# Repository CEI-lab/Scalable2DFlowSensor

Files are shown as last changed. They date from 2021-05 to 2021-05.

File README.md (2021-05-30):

# Scalable2DFlowSensor

Repository for paper, A Customizable, Low-Cost Alternative for Distributed 2D Flow Sensing in Swarms, published in SWARMS2021 conference. 

This is an implementation of a 2D thermal flow sensor that uses a PCB with central heating element and 5 surrounding thermistors to sense both magnitude and direction of flow along a surface. See paper for details https://cei.ece.cornell.edu/publications/

This work is published for the purpose of helping other groups design their own thermal flow sensors. Details for use:

The calibration code folder contains the python and arduino code used in the calibration of the sensor. The sensor was designed to be read from any microcontroller with an analog read, we chose to use an arduino. The python code is then run from a computer connected over usb to the device to read data from the sensor. The purpose of this calibration is to find the proper offset values for accurate reading of direction and magnitude.

The field_test_code folder contains the python and arduino files used to read data from the sensor in the field. These files are quite simple because a key goal of the sensor was a simple interface. Even the arduino is overkill for this application. The python file here periodically saves the read data to a csv file with a unique generated file name. The test is concluded by interrupting the script with a keyboard interrupt which is caught and saves the remaining data to the file before terminating.

The other three folders flowSensorFlexible, flowSensorV2, and magArraySensor contain the PCB design files for the 3 versions of the sensor discussed. These files were created in Altium and can be used as is to order your own PCBs or can serve as inspiration to design your own geometries. These designs are quite simple, so recreating them in another program or to different specificiation should be straigh forward.

Published under the MIT Open Source Liscense.

Maintained by Jack A. Defay (user: jackdefay).

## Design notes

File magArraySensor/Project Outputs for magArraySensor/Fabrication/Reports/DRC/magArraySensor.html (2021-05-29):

Altium

# Design Rule Verification Report

Date: | | 8/11/2020
Time: | | 11:37:09 PM
Elapsed Time: | | 00:00:01
Filename: | | C:\Users\3jack\AppData\Local\TempReleases\Snapshot\3\magArraySensor.PcbDoc

Warnings: | | 0
Rule Violations: | | 0

## Summary

Warnings | Count
Total | 0

Rule Violations | Count
Clearance Constraint (Gap=10mil) (All),(All) | 0
Short-Circuit Constraint (Allowed=No) (All),(All) | 0
Un-Routed Net Constraint ( (All) ) | 0
Modified Polygon (Allow modified: No), (Allow shelved: No) | 0
Width Constraint (Min=10mil) (Max=10mil) (Preferred=10mil) (Disabled)(All) | 0
Power Plane Connect Rule(Relief Connect )(Expansion=20mil) (Conductor Width=10mil) (Air Gap=10mil) (Entries=4) (All) | 0
Hole Size Constraint (Min=1mil) (Max=100mil) (All) | 0
Hole To Hole Clearance (Gap=10mil) (All),(All) | 0
Minimum Solder Mask Sliver (Gap=10mil) (All),(All) | 0
Silk To Solder Mask (Clearance=10mil) (IsPad),(All) | 0
Silk to Silk (Clearance=10mil) (All),(All) | 0
Net Antennae (Tolerance=0mil) (All) | 0
Height Constraint (Min=0mil) (Max=1000mil) (Prefered=500mil) (All) | 0
Total | 0

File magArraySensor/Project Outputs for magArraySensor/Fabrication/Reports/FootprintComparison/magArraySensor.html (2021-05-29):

Altium customize

# Footprint Comparison Report

Date: | | 8/11/2020
Time: | | 11:37:11 PM
Elapsed Time: | | 00:00:00
Filename: | | C:\Users\3jack\AppData\Local\TempReleases\Snapshot\3\magArraySensor.PcbDoc

## Contents

Contents

Components Status Summary

Matched Components List

## Components Status Summary

## Matched Components List

Designator | Footprint | Footprint reference | Footprint to reference Library
J1 | PIN | PIN | C:\Users\3jack\AppData\Local\TempReleases\Snapshot\3\PcbLib1.PcbLib
J2 | PIN | PIN | C:\Users\3jack\AppData\Local\TempReleases\Snapshot\3\PcbLib1.PcbLib
J3 | PIN | PIN | C:\Users\3jack\AppData\Local\TempReleases\Snapshot\3\PcbLib1.PcbLib
J4 | PIN | PIN | C:\Users\3jack\AppData\Local\TempReleases\Snapshot\3\PcbLib1.PcbLib
J5 | PIN | PIN | C:\Users\3jack\AppData\Local\TempReleases\Snapshot\3\PcbLib1.PcbLib
J6 | PIN | PIN | C:\Users\3jack\AppData\Local\TempReleases\Snapshot\3\PcbLib1.PcbLib
J7 | PIN | PIN | C:\Users\3jack\AppData\Local\TempReleases\Snapshot\3\PcbLib1.PcbLib
J8 | PIN | PIN | C:\Users\3jack\AppData\Local\TempReleases\Snapshot\3\PcbLib1.PcbLib
J9 | PIN | PIN | C:\Users\3jack\AppData\Local\TempReleases\Snapshot\3\PcbLib1.PcbLib
J10 | PIN | PIN | C:\Users\3jack\AppData\Local\TempReleases\Snapshot\3\PcbLib1.PcbLib
J11 | PIN | PIN | C:\Users\3jack\AppData\Local\TempReleases\Snapshot\3\PcbLib1.PcbLib
J12 | PIN | PIN | C:\Users\3jack\AppData\Local\TempReleases\Snapshot\3\PcbLib1.PcbLib
R1 | RESC2013X60X35LL10T20 | RESC2013X60X35LL10T20 | Altium Content Vault
R2 | RESC2013X60X35LL10T20 | RESC2013X60X35LL10T20 | Altium Content Vault
R3 | RESC2013X60X35LL10T20 | RESC2013X60X35LL10T20 | Altium Content Vault
R4 | RESC2013X60X35LL10T20 | RESC2013X60X35LL10T20 | Altium Content Vault
R5 | RESC2013X60X35LL10T20 | RESC2013X60X35LL10T20 | Altium Content Vault
R6 | RESC2013X60X35LL10T20 | RESC2013X60X35LL10T20 | Altium Content Vault
R7 | RESC2013X60X35LL10T20 | RESC2013X60X35LL10T20 | Altium Content Vault
R8 | RESC2013X60X35LL10T20 | RESC2013X60X35LL10T20 | Altium Content Vault
R9 | RESC2010(5025)_N | RESC2010(5025)_N | Altium Content Vault
R10 | RESC2010(5025)_N | RESC2010(5025)_N | Altium Content Vault
R11 | RESC2010(5025)_N | RESC2010(5025)_N | Altium Content Vault
R12 | RESC2010(5025)_N | RESC2010(5025)_N | Altium Content Vault
R13 | RESC2010(5025)_N | RESC2010(5025)_N | Altium Content Vault
R14 | RESC2010(5025)_N | RESC2010(5025)_N | Altium Content Vault
R15 | RESC2010(5025)_N | RESC2010(5025)_N | Altium Content Vault
R16 | RESC2010(5025)_N | RESC2010(5025)_N | Altium Content Vault
RT1 | THERMISTOR | thermistor | C:\Users\3jack\AppData\Local\TempReleases\Snapshot\3\PcbLib1.PcbLib
RT2 | THERMISTOR | thermistor | C:\Users\3jack\AppData\Local\TempReleases\Snapshot\3\PcbLib1.PcbLib
RT3 | THERMISTOR | thermistor | C:\Users\3jack\AppData\Local\TempReleases\Snapshot\3\PcbLib1.PcbLib
RT4 | THERMISTOR | thermistor | C:\Users\3jack\AppData\Local\TempReleases\Snapshot\3\PcbLib1.PcbLib
RT5 | THERMISTOR | thermistor | C:\Users\3jack\AppData\Local\TempReleases\Snapshot\3\PcbLib1.PcbLib
RT6 | THERMISTOR | thermistor | C:\Users\3jack\AppData\Local\TempReleases\Snapshot\3\PcbLib1.PcbLib
RT7 | THERMISTOR | thermistor | C:\Users\3jack\AppData\Local\TempReleases\Snapshot\3\PcbLib1.PcbLib
RT8 | THERMISTOR | thermistor | C:\Users\3jack\AppData\Local\TempReleases\Snapshot\3\PcbLib1.PcbLib

Back to top

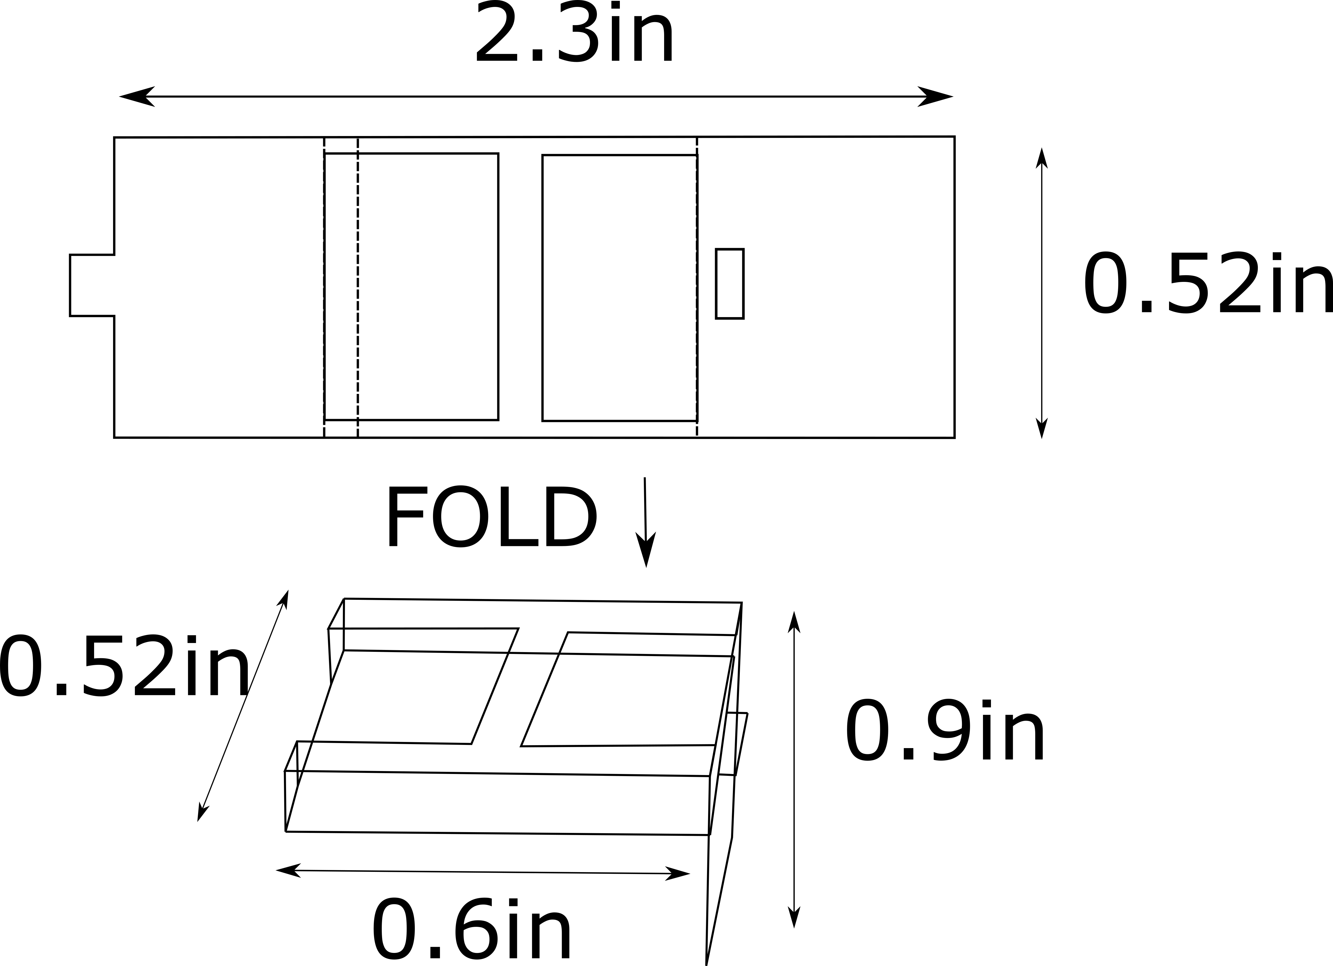
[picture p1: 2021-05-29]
flowSensorFlexible/foldDiagram.png

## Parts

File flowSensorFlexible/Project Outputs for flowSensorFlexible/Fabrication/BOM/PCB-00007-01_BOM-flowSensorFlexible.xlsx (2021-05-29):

Designator | Manufacturer | MPN | Quantity | Description | Sierra DNI
J1 |  |  | 1
J2 |  |  | 1
J3 |  |  | 1
J4, J5, J6, J7, J8 |  |  | 5
J9, J10, J11, J12, J13, J14, J15, J16, J17, J18, J19, J20, J21, J22, J23 |  |  | 15
R1, R2, R3, R4, R5 | Yageo | RC0805FR-0710KL | 5 | RES 10.0K OHM 1/8W 1% 0805 SMD
R6 | TE Connectivity Passive Product | 3502100RFT | 1 | 100 Ohms ±1% 2W Chip Resistor 2010 (5025 Metric) Thick Film
RT1, RT2, RT3, RT4, RT5 | Murata | NTCS0805E3103FLT | 5 | Chip Thermistor, 10 KOhm, +/- 5%, 200 mW, -40 to 125 degC, 0805 (2012 Metric), RoHS, Tape and Reel

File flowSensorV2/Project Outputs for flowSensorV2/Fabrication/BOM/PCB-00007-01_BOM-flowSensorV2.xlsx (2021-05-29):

Designator | Manufacturer | MPN | Quantity | Description | Sierra DNI
J1, J3 |  |  | 2
J2, J4, J5, J6, J7, J8 |  |  | 6
R1, R2, R3, R4, R5 | Yageo |  | 5 | Chip Resistor, 10 KOhm, +/- 1%, 0.125 W, -55 to 155 degC, 0805 (2012 Metric), RoHS, Tape and Reel
R6 |  |  | 1 | 16R9 0.75W 1% 2010 (5025 Metric) SMD
RT1, RT2, RT3, RT4 |  |  | 4 | THERMISTOR NTC 10KOHM 3900K 0805
RT5 |  |  | 1

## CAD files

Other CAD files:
flowSensorFlexible/Project Outputs for flowSensorFlexible/Fabrication/ExportSTEP/flowSensorFlexible.x_t
flowSensorFlexible/Project Outputs for flowSensorFlexible/Sources/ExportSTEP/flowSensorFlexible.x_t
flowSensorV2/Project Outputs for flowSensorV2/Fabrication/ExportSTEP/flowSensorV2.x_t
flowSensorV2/Project Outputs for flowSensorV2/Sources/ExportSTEP/flowSensorV2.x_t

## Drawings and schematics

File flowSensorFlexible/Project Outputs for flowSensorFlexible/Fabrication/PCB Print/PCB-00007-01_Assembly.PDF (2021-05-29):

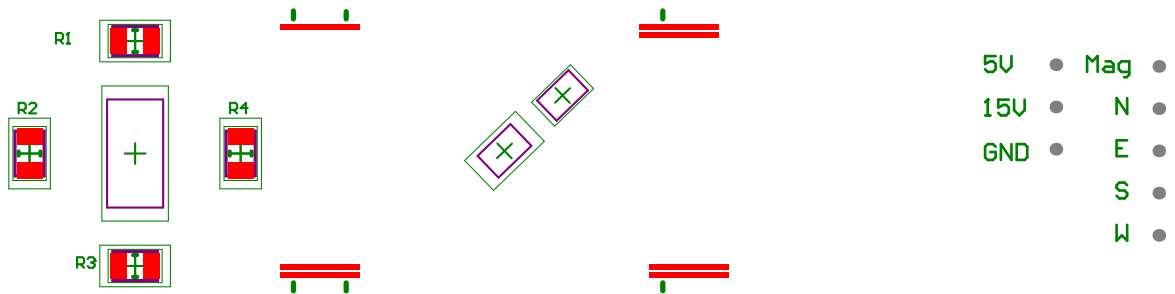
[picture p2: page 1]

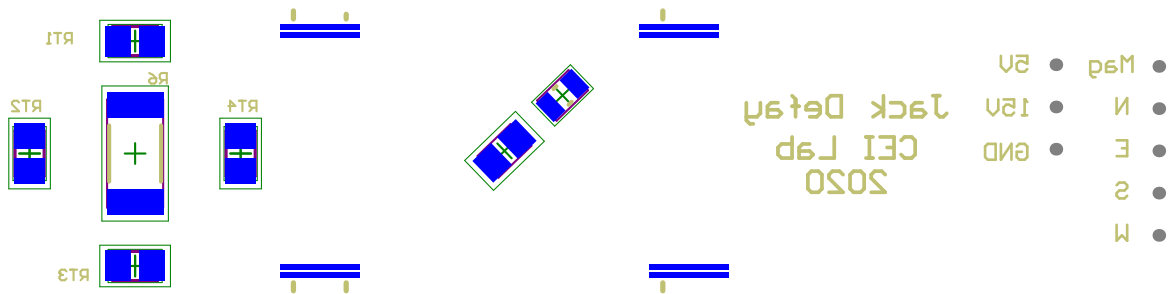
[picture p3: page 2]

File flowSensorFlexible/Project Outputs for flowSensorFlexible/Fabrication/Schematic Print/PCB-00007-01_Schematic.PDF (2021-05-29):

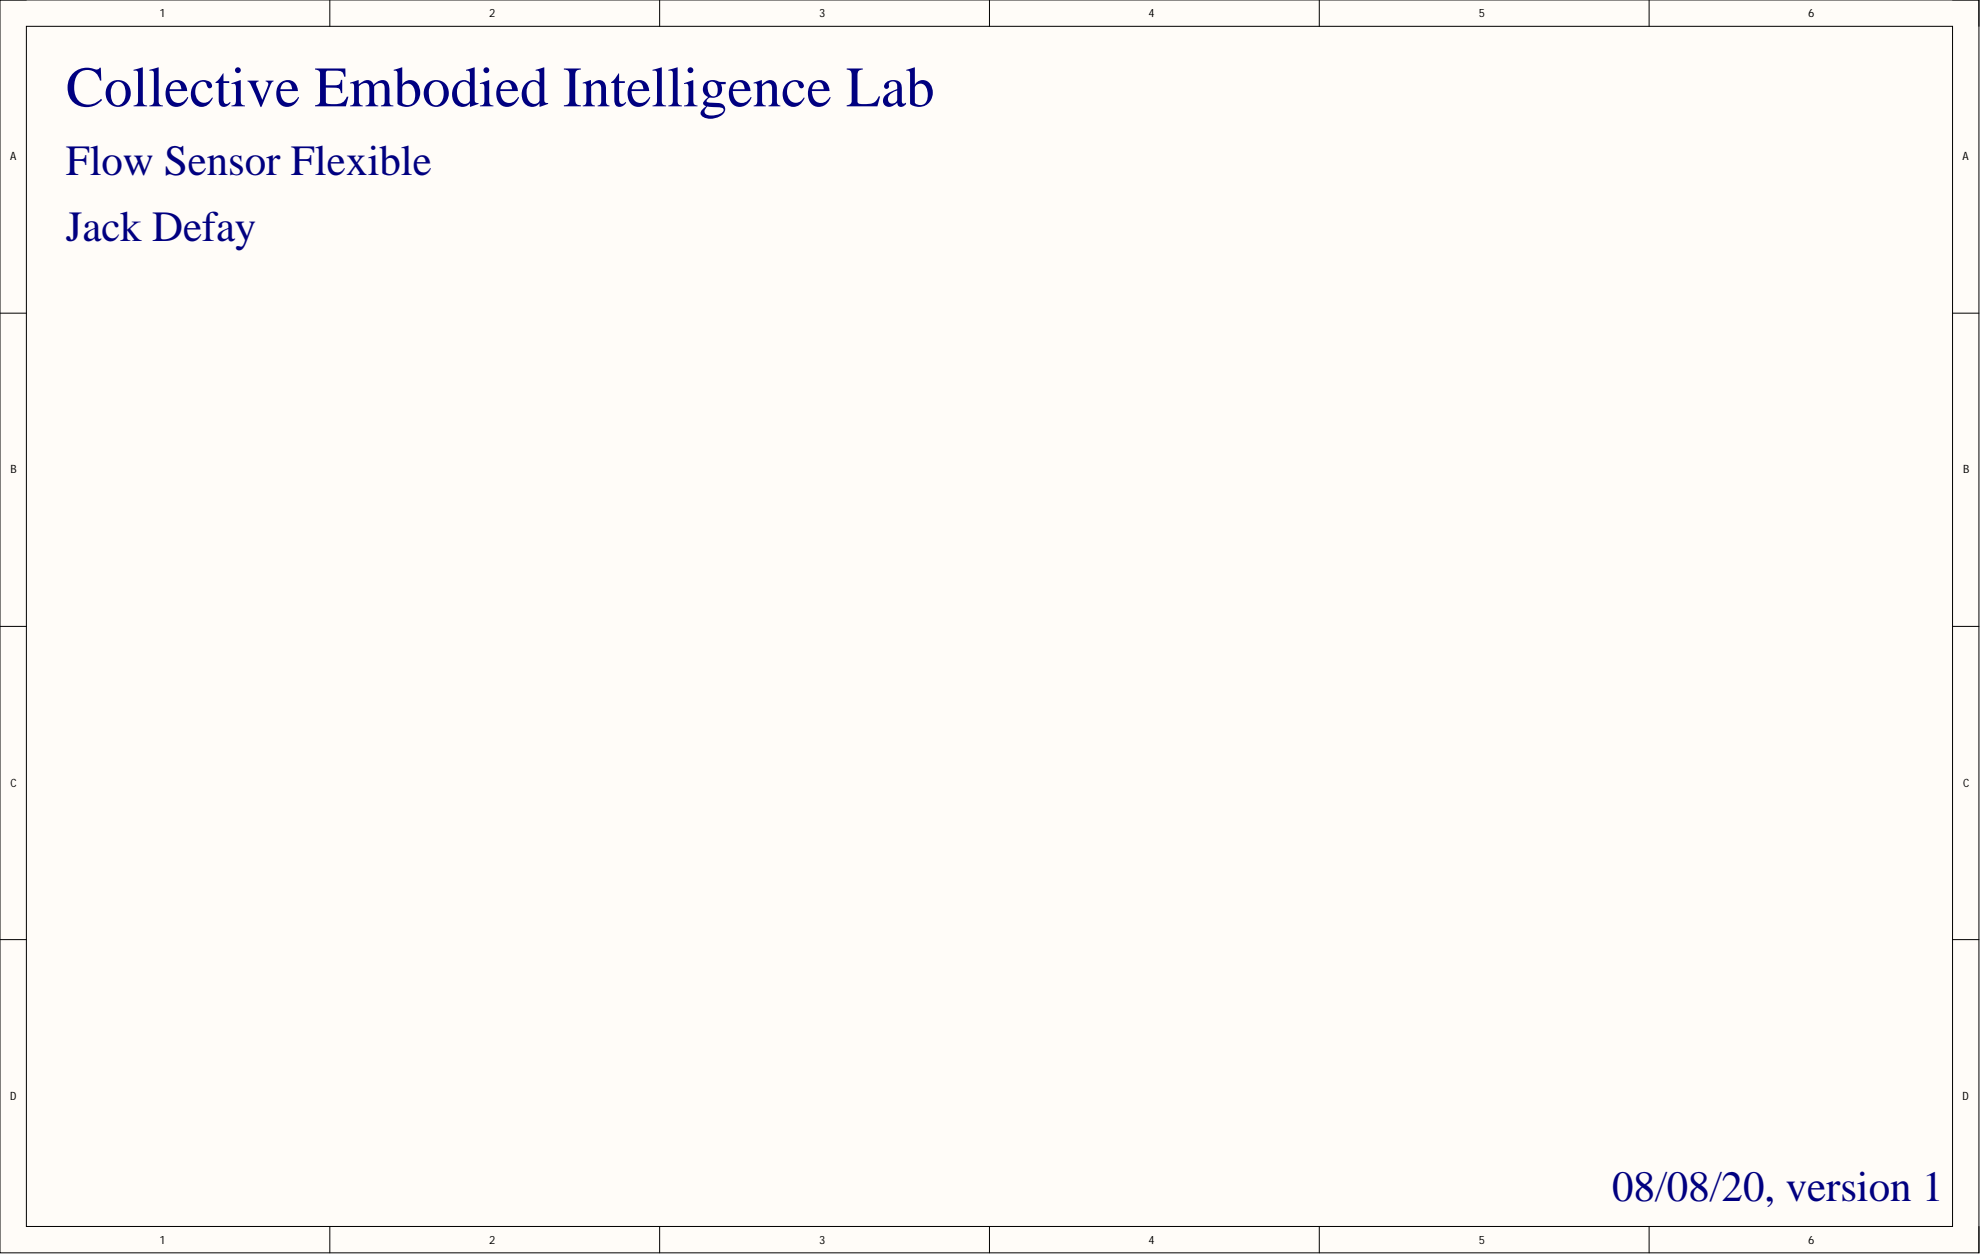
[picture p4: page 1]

Collective Embodied Intelligence Lab

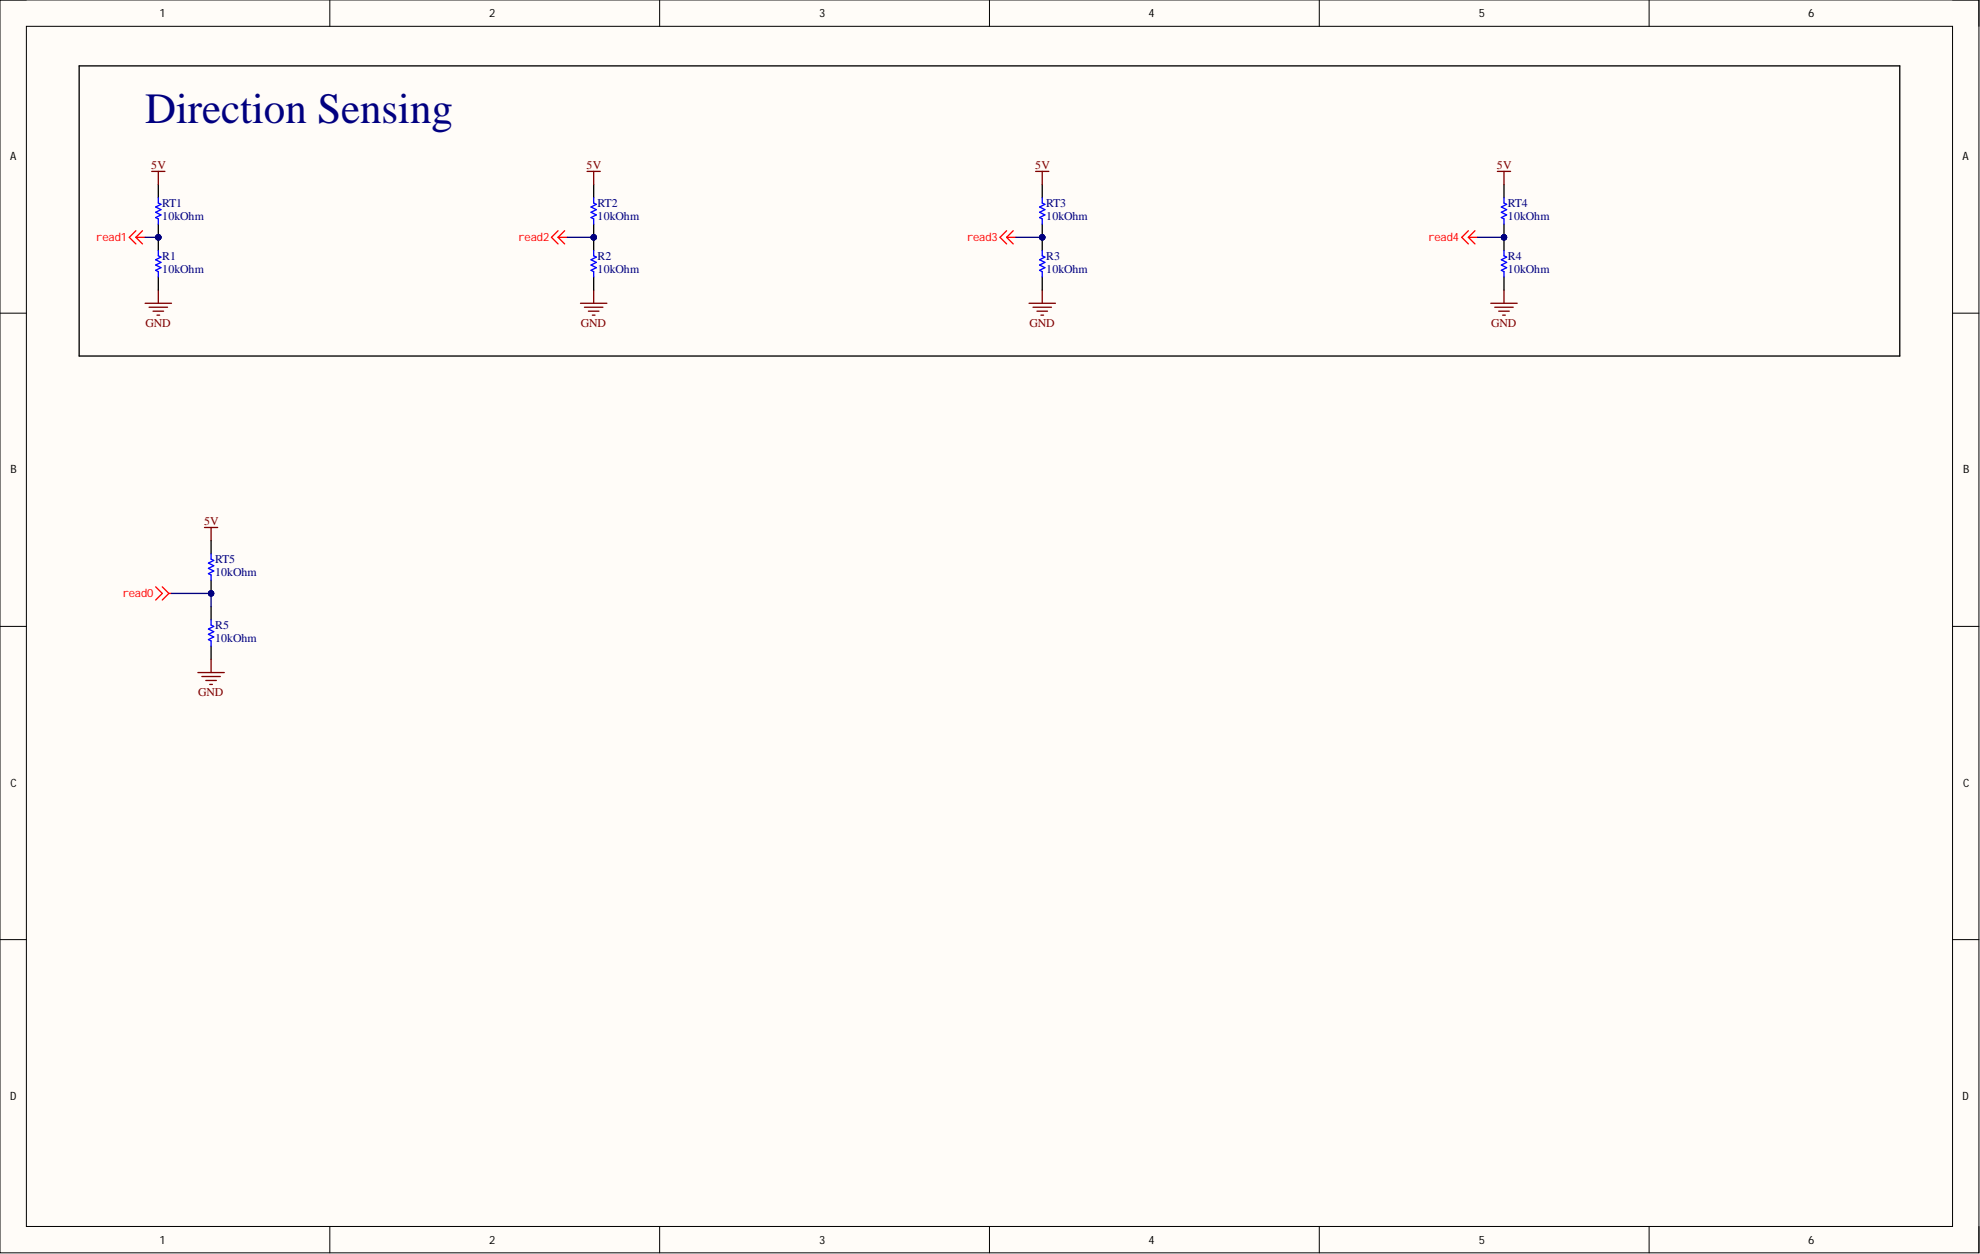
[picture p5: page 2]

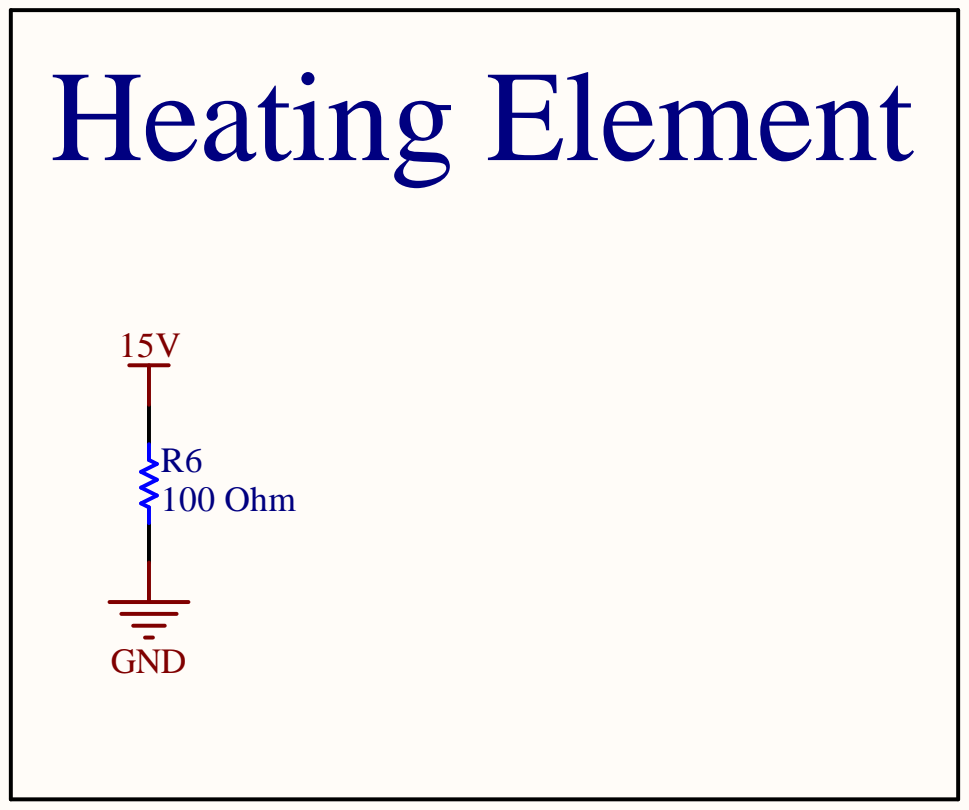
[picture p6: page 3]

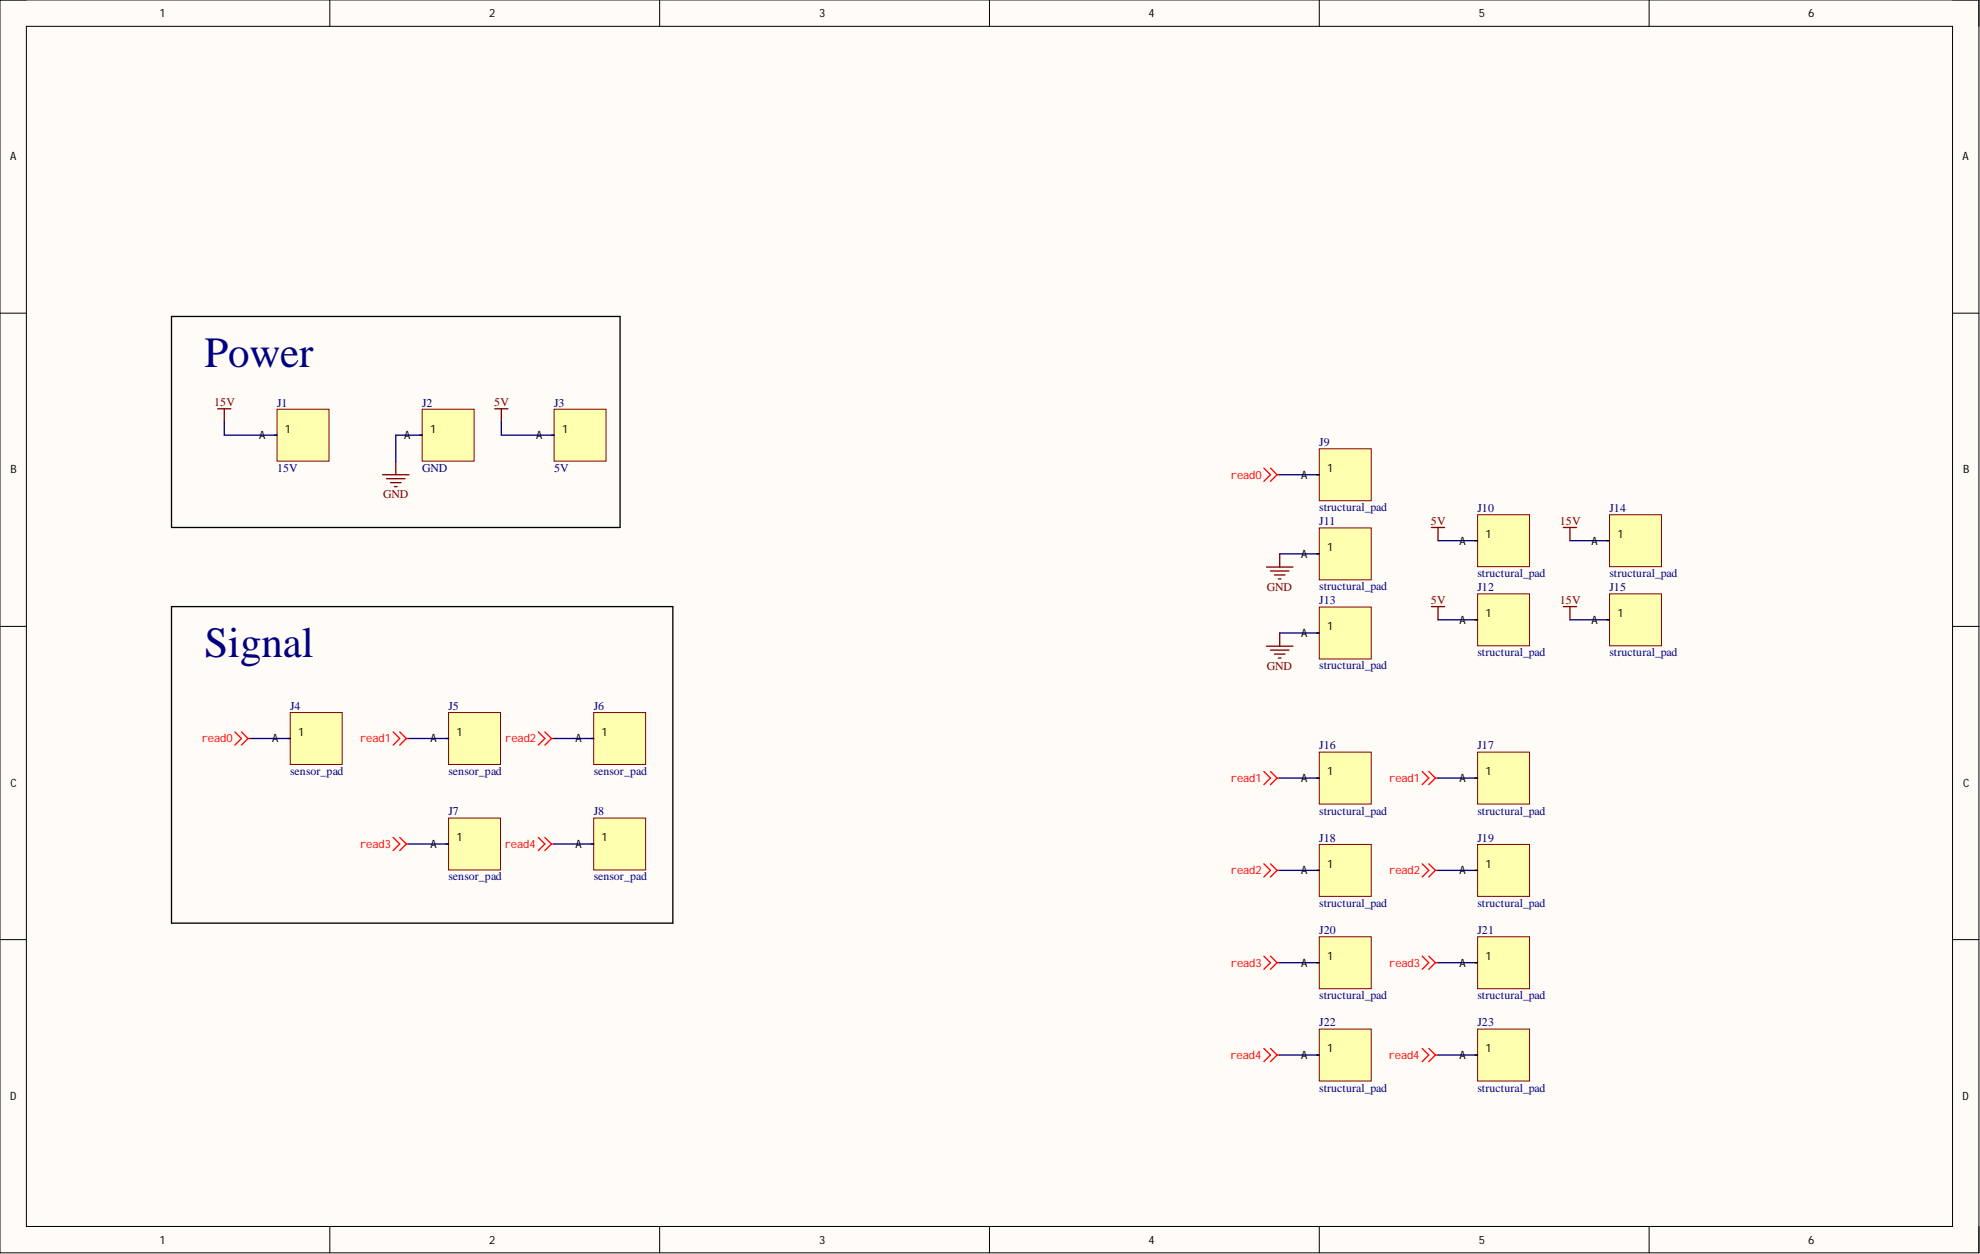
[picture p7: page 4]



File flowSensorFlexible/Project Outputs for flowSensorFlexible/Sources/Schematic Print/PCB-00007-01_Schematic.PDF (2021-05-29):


Collective Embodied Intelligence Lab




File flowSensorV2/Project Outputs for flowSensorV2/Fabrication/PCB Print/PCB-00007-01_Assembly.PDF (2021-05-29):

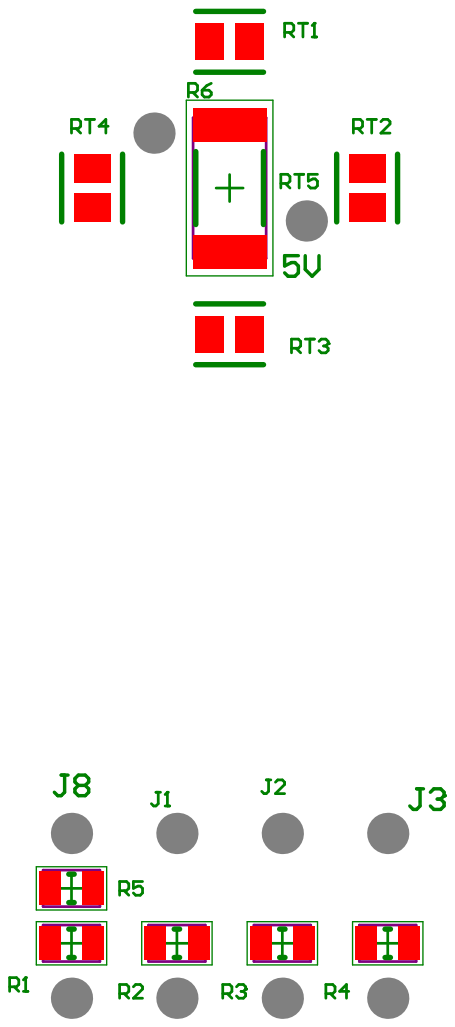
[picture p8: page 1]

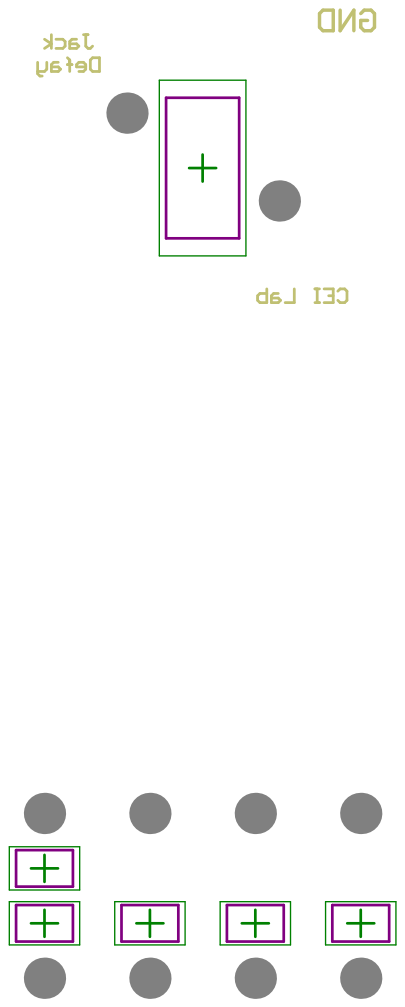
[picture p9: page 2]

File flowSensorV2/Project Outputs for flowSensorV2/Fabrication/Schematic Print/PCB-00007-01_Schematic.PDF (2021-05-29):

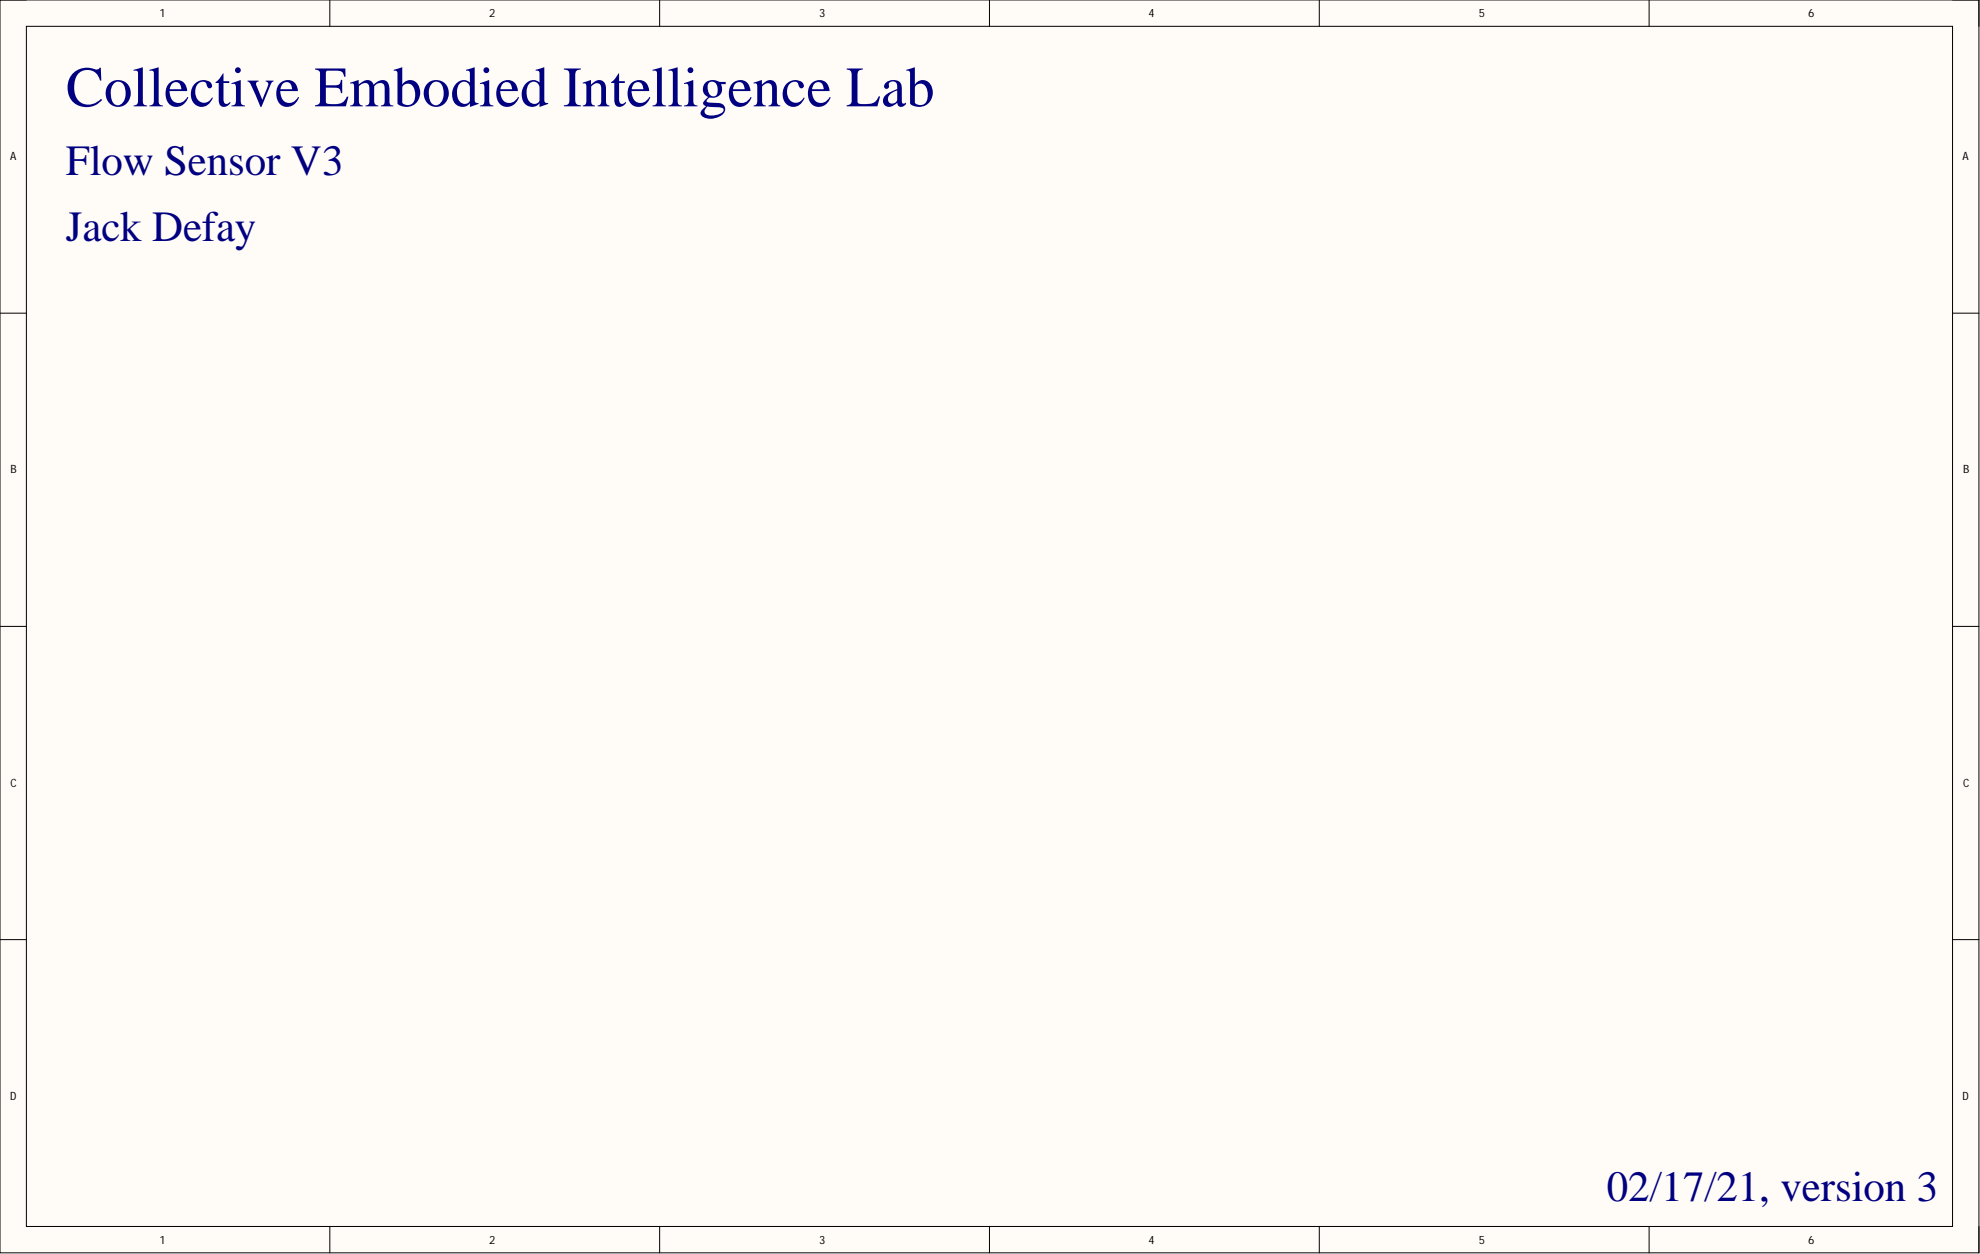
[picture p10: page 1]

Collective Embodied Intelligence Lab

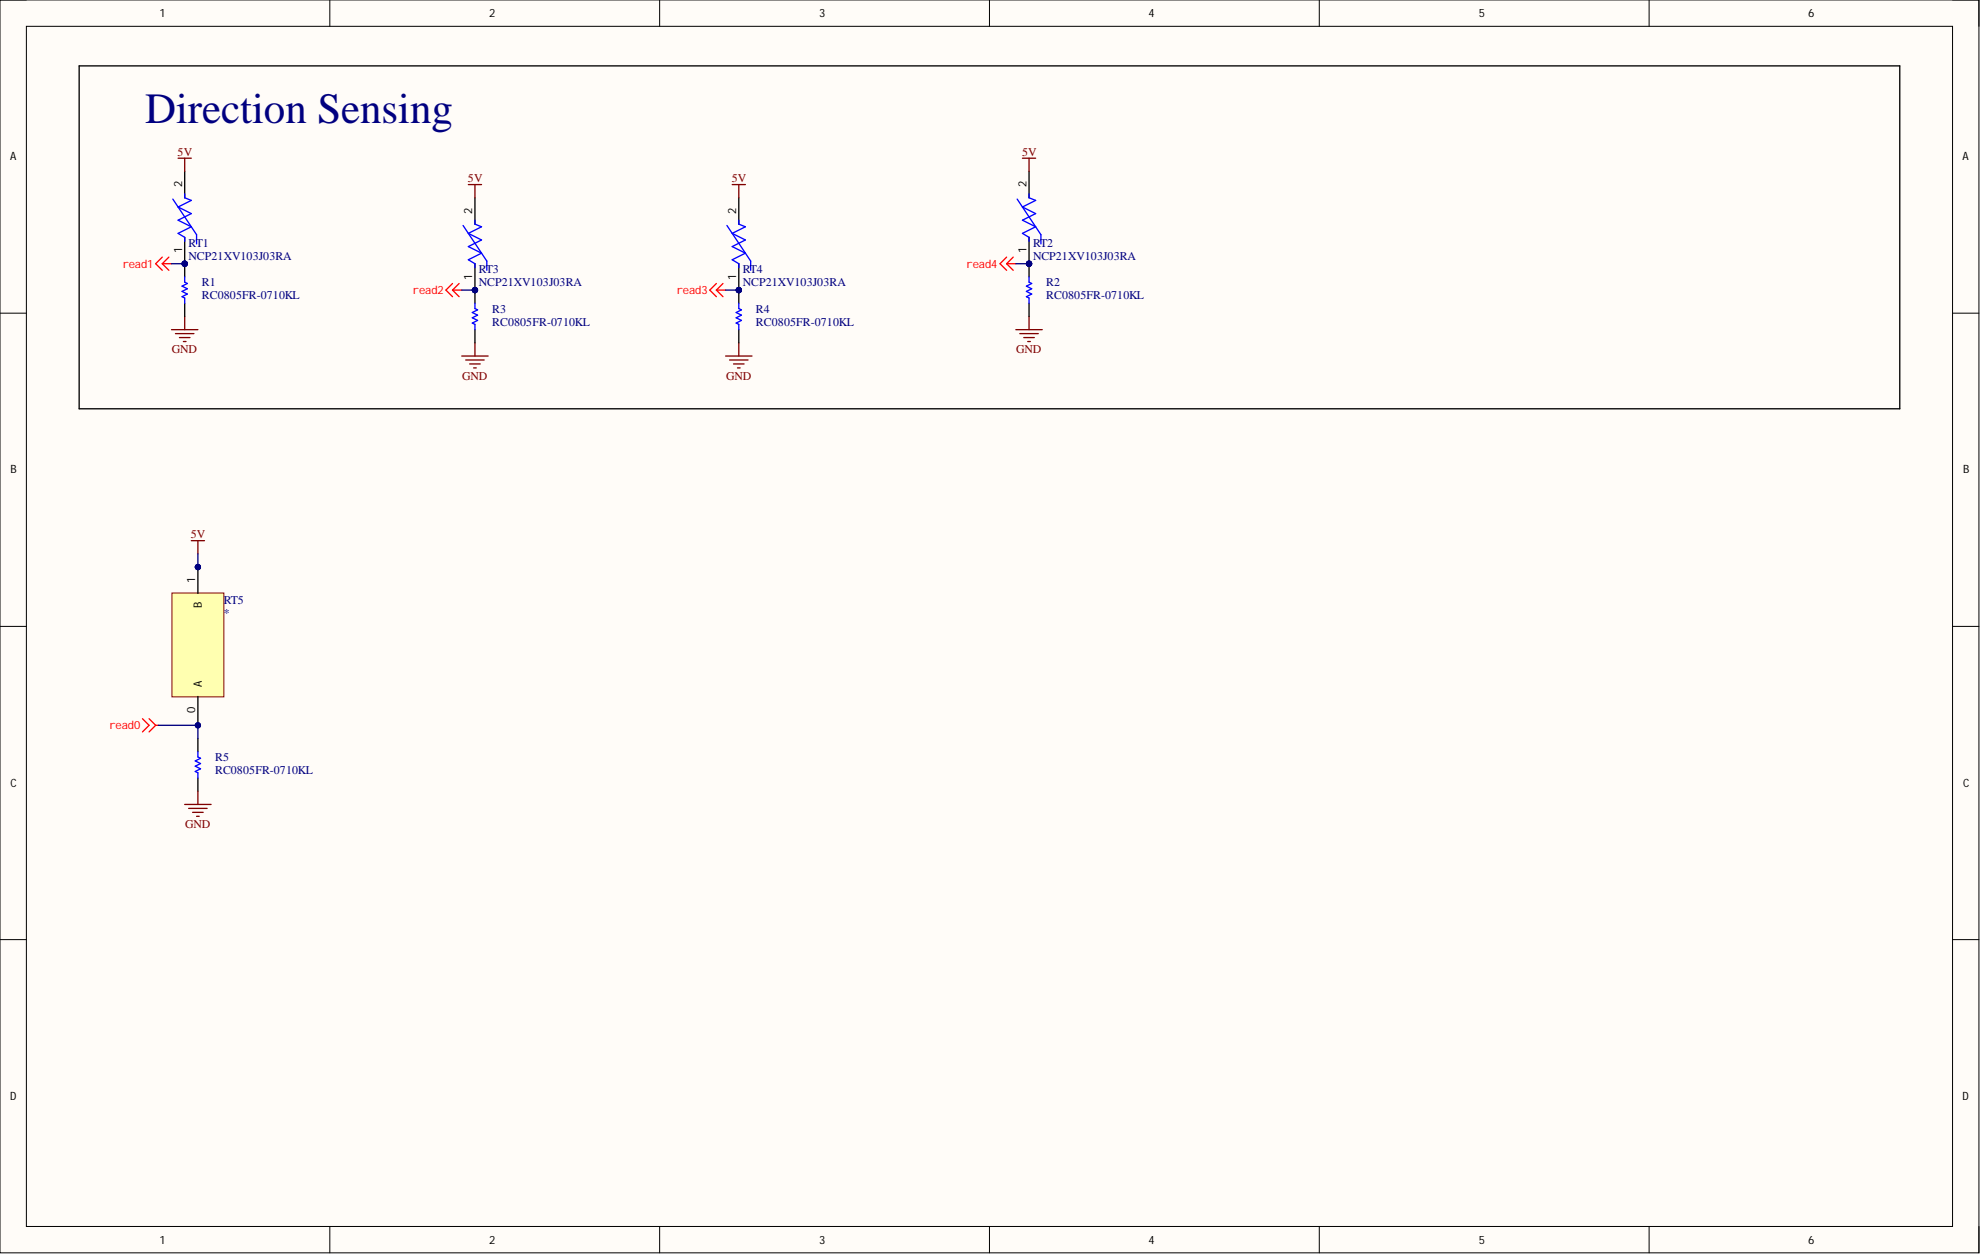
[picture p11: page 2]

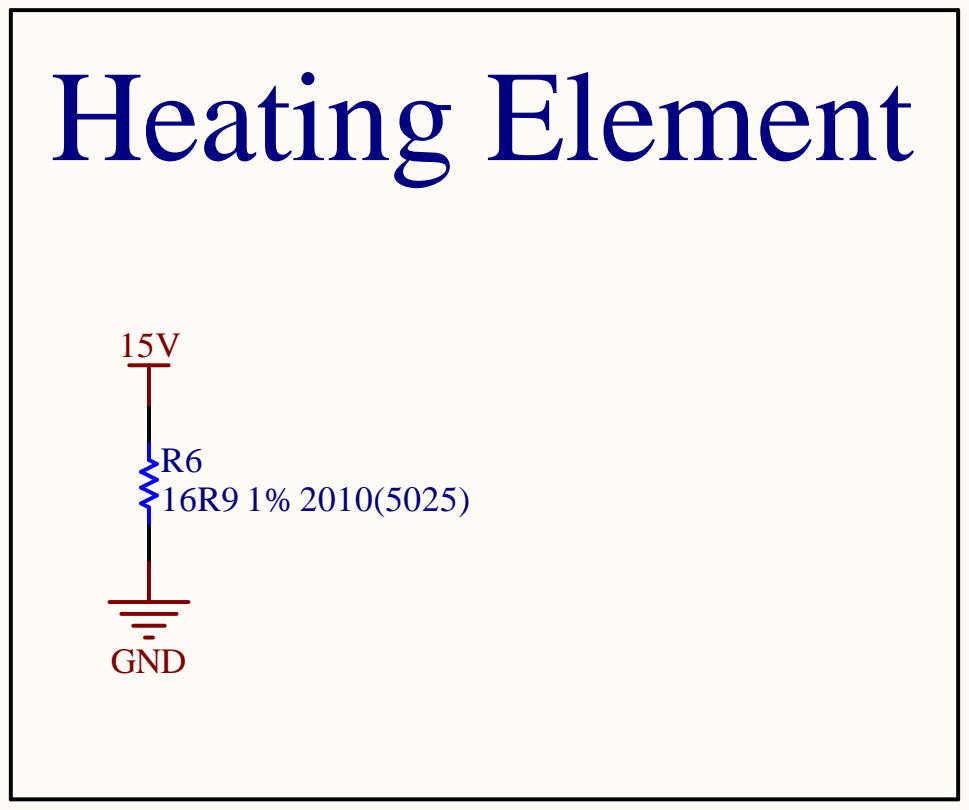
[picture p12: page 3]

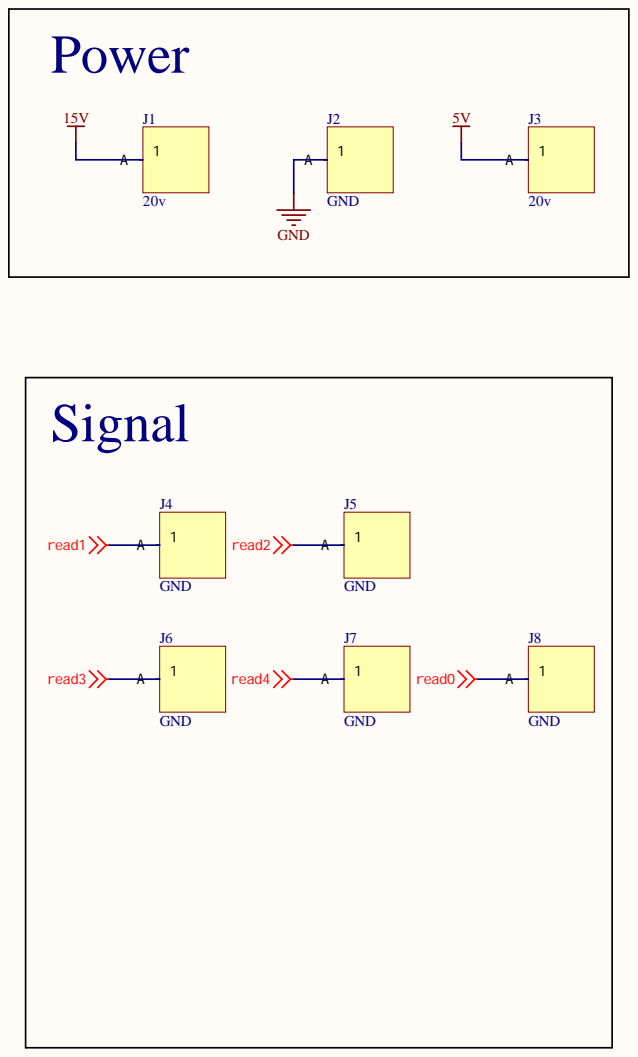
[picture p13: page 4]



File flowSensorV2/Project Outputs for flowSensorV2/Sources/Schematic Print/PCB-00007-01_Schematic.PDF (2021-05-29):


Collective Embodied Intelligence Lab




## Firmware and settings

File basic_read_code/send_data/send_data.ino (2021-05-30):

/*
 * Created 05/30/21
 * By Jack A. Defay
 * 
 * Code for reading the raw analog values from the sensor.
 * 
 * This code is published under the MIT Open Source Liscense
 */

#include <math.h>

int ThermistorMag = A0;  //thermistor 5
int ThermistorN = A1;  //thermistor 8
int ThermistorE = A2;  //thermistor 2
int ThermistorS = A3;  //thermistor 7
int ThermistorW = A4;  //thermistor 6

int pins[] = {ThermistorN, ThermistorE, ThermistorS, ThermistorW};
double data[4];
double mag;

void setup() {
  pinMode(ThermistorMag, INPUT);
  pinMode(ThermistorN, INPUT);
  pinMode(ThermistorE, INPUT);
  pinMode(ThermistorS, INPUT);
  pinMode(ThermistorW, INPUT);
  
  
  Serial.begin(9600);
}

void loop() {
  Serial.print(millis());
  Serial.print(", ");
  
  mag = analogRead(ThermistorMag);
  Serial.print(mag);
  Serial.print(", ");


  for(int n=0; n<4; n++){
    data[n] = analogRead(pins[n]);
    Serial.print(data[n]);
    Serial.print(", ");
  }
  Serial.println();

  delay(100);
}

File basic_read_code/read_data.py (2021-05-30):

# Created 05/30/21
# By Jack A. Defay
#
# Code for reading the magnitude and angle data from the sensor as raw analog outputs.
#
# This code is published under the MIT Open Source Liscense

import numpy as np
import pandas as pd
import serial
import time


#setup time
start_time = time.time()

#set save file name
t = time.localtime()
filename = str(t.tm_mon) + str(t.tm_mday) + str(t.tm_year) + '_experiment_' + str(t.tm_hour) + '.' + str(t.tm_min) + '.' + str(t.tm_sec)  + '.csv'

#setup dataframe
df = pd.DataFrame([[start_time,1,2,3,4,5,6,7]], columns=['time', 'mag', 'North', 'East', 'South', 'West'])
df.to_csv(path_or_buf=filename, mode='a', index=False)
df = pd.DataFrame(None)

#setup the serial line
ser = serial.Serial('COM9', 115200)
time.sleep(2)

def readArduino(df):
    string = ''
    ser.reset_input_buffer()
    while(ser.in_waiting < 1):
        c=0
    
    while(len(string) < 13):
        b = ser.readline()
        string_n = b.decode()
        string = string_n.rstrip()
        # print(int(time.time() - start_time) ,repr(string), sep=": ")

    stringArray = []
    stringArray = string.split(", ")
    magnitudeArray = []
    for cell in stringArray:
        # print(cell)
        magnitudeArray.append(int(cell))

    return addData(df, [magnitudeArray])

def addData(df, magnitudeArray):
    magnitudeArray[0].insert(0, (time.time() - start_time))
    if(not len(magnitudeArray[0]) == 6):
        magnitudeArray = [[0,0,0,0,0,0]]
    frame = pd.DataFrame(magnitudeArray, columns=['time', 'mag', 'North', 'East', 'South', 'West'])
    print(frame)
    return pd.concat([df, frame], axis=0)

while(True):
    try:
        df = readArduino(df)
        if(df.shape[0]%100 == 0):
            df.to_csv(path_or_buf=filename, mode='a', index=False, header=False)
            df = pd.DataFrame(None)
    except KeyboardInterrupt:
        df.to_csv(path_or_buf=filename, mode='a', index=False, header=False)
        print(df)
        print(filename)
        raise
